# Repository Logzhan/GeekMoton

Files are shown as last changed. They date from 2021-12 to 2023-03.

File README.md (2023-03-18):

# GeekMotion

2023-03-19：经过测试发现稚晖君的Peak和GeekMotion一样存在电量显示不稳定、充电充不满的问题，计划基于Peak优化部分电路，另外发现Peak测量的电压偏低

**功能描述：类似稚晖君Peak的小组件，手持嵌入式移动终端。**

- WIFI通信功能
- IMU、MAG传感器。
- 采用原生ESP-IDF开发，移植X-Track交互框架 + LVGL。
- LettleShell命令行模块，可以采用命令行和ESP32交互。
- 计步器
- 运动识别(待实现)
- 电梯识别(待实现)
- SD卡存储

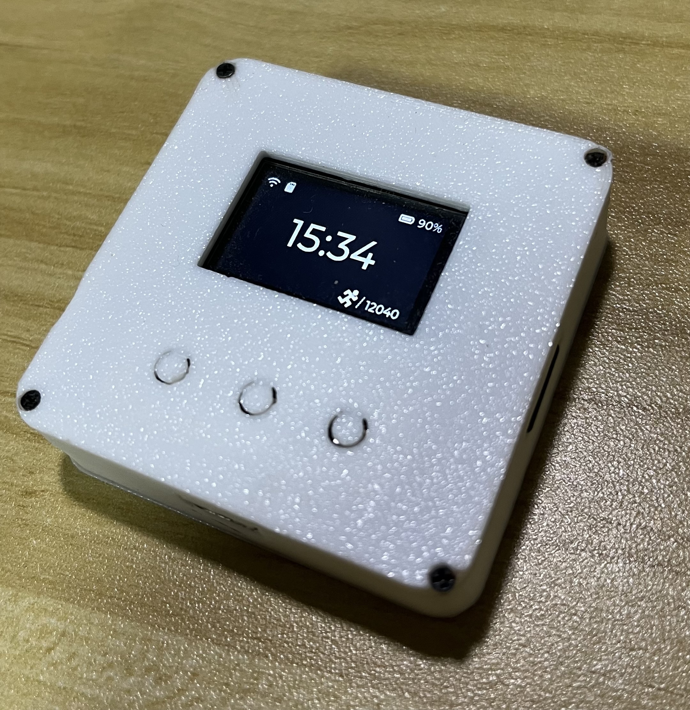
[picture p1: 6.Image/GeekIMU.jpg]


命令行支持(移植letter shell)：

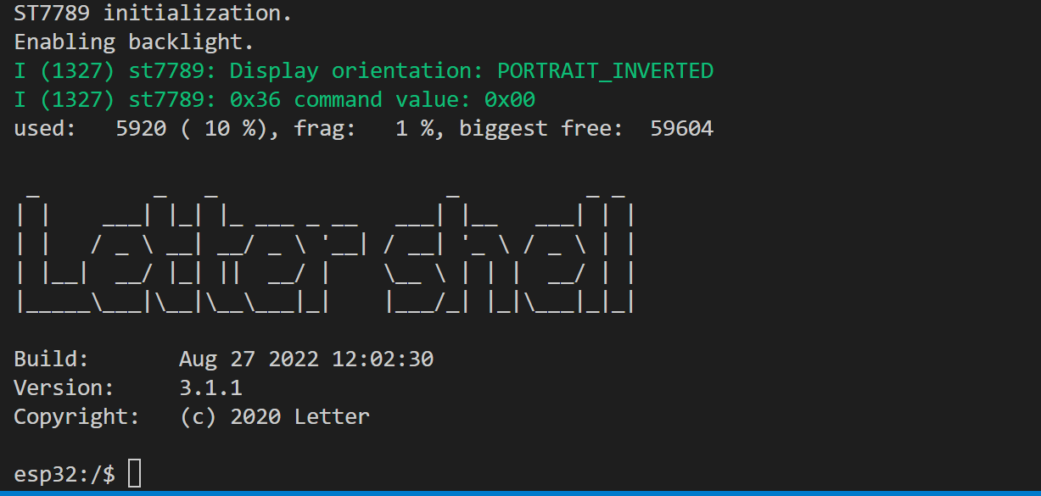
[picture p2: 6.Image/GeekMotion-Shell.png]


支持：

- 命令行自动补全
- 历史命令行记忆
- ...

**更新日志：**

**2022-08-23 ：** 1) 修改lettleSell部分函数，修改void为返回值为int, 减少由于函数指针转换造成的GCC Warning。2) 优化Page/SystemInfosModel.cpp，定义部分结构体后，采用memset函数初始化，减少GCC Warning。3）优化Page\StartUp部分宏定义、减少GCC Warning。 4）注释部分不使用函数，减少GCC Warning。

**2022-08-24 ：** 1）去掉visual studio的ARM和ARM64工程 2）隐藏LVGL在MSVC时产生的类型转换警告 3）加入CleanProject.bat脚本可以快速清理Visual Studio生成的pch和obj等临时文件。

**2022-08-27 ：**  1) 更新计步器功能 

**2022-08-28 :**    1）清除无用X-Track框架代码 2）移除Visual Studio x64工程只保留win32工程，最大程度复原Cotex-m 32位环境 

**lettleShell移植支持说明：** 需要适配esp32的ld文件。

样例：
C:\Users\Administrator\esp\esp-idf\components\esp32\ld\
在这个文件夹里面，把原来的esp32.project.ld.in替换当前目前的id文件，用于支持命令行，替换前记得备份

```c++
  /* 核心原理是找到这个.flash.appdesc, 然后加入_shell_command_start和*_shell_command_end/  
.flash.appdesc : ALIGN(0x10)
  {
    _rodata_start = ABSOLUTE(.);

    *(.rodata_desc .rodata_desc.*)               /* Should be the first.  App version info.        DO NOT PUT ANYTHING BEFORE IT! */
    *(.rodata_custom_desc .rodata_custom_desc.*) /* Should be the second. Custom app version info. DO NOT PUT ANYTHING BEFORE IT! */
	
	_shell_command_start = ABSOLUTE(.);
	KEEP (*(shellCommand))
	_shell_command_end = ABSOLUTE(.);

    /* Create an empty gap within this section. Thanks to this, the end of this
     * section will match .flah.rodata's begin address. Thus, both sections
     * will be merged when creating the final bin image. */
    . = ALIGN(ALIGNOF(.flash.rodata));
  } >default_rodata_seg
```

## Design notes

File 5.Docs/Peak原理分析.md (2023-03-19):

## Peak电路原理分析



### 一、开机电路分析

		用户在按下EC_KEY之后，EC_KEY会被拉低电平，此时Q1的栅极会被拉低电平 。此时Q1导通，单片机的系统进入有电状态，ESP32启动。此时有两种情况。1）用户立即放下按钮：此时PWR_EN还没及时拉高，Q2这个NMOS管始终处于不导通状态。Q1会处于不导通状态，系统关机。 2）用户持续按下EC_KEY此时：单片机持续运行，PWR_EN被持续拉高，Q2始终会处于导通状态，Q1的栅极会被拉低，系统始终保持有电状态。

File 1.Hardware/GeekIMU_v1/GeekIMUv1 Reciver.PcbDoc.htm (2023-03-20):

Reporting Options

# File in Previous Format

Date | : | 2023/3/20
Time | : | 21:13:47
Filename | : | Y:\Hardware Project\Geek IMU\GeekIMU v1\1.Hardware\GeekIMUv1 Reciver.PcbDoc

Version | Warning
Summer 09 | CAUTION - File contains old violation objects. These violations are no longer supported & will not be loaded. Please run DRC after opening this file in order to refresh the violations.
Summer 09 | CAUTION - Existing testpoint rules and settings are used as fabrication testpoint information.
Release 12 | CAUTION - Air Gap Width previously controlled by Clearance rule is now controlled by Polygon Connect Style rule's newly introduced Air Gap Width (set to default value). Suggest reviewing each Polygon Connect Style rule's Air Gap Width attribute for correctness.
Release 13 | CAUTION - Silkscreen Over Component Pads Rules are converted to Silk To Solder Mask Clearance Rules. Suggest examining rule scopes for accuracy.

This file was generated by an earlier version of the software

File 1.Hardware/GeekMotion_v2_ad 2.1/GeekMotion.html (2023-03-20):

Altium customize

# Board Information Report

Date: | | 2023/3/20
Time: | | 5:40:24
Elapsed Time: | | 00:00:00
Filename: | | E:\Hardware Project\GeekMotion\1.Hardware\GeekMotion_v2_ad 2.1\GeekMotion.PcbDoc
Units: | | mmmils

## Contents

Contents

Board Specification

General

Routing

Routing Information

Layer Information

Layer Information

Drill Pairs

Board Holes

Non-Plated Hole Size

Plated Hole Size

Board Slots

Non-Plated Slot Size

Plated Slot Size

Board Square Holes

Non-Plated Square Hole Size

Plated Square Hole Size

Other

Top Layer Annular Ring Size

Mid Layer Annular Ring Size

Bottom Layer Annular Ring Size

Pad Solder Mask

Pad Paste Mask

Pad Pwr/Gnd Expansion

Pad Relief Conductor Width

Pad Relief Air Gap

Pad Relief Entries

Via Solder Mask

Via Pwr/Gnd Expansion

Track Width

Arc Line Width

Arc Radius

Arc Degrees

Text Height

Text Width

Net Track Width

Net Via Size

## Board Specification

General
Board Size | 1240mils x 1340mils
Components on board | 66

Back to top

## Routing

Routing Information
Routing completion | 100.00%
Connections | 184
Connections routed | 184
Connections remaining | 0

Back to top

## Layer Information

Layer | Arcs | Pads | Vias | Tracks | Texts | Fills | Regions | ComponentBodies
Top1 | 0 | 12 | 0 | 150 | 0 | 0 | 48 | 0
Signal2 | 0 | 0 | 0 | 177 | 0 | 0 | 37 | 0
Gnd3 | 0 | 0 | 0 | 0 | 0 | 0 | 2 | 0
Bottom4 | 2 | 277 | 0 | 367 | 0 | 0 | 247 | 0
Mechanical 1 | 0 | 0 | 0 | 66 | 0 | 0 | 0 | 18
Mechanical 2 | 0 | 0 | 0 | 0 | 0 | 0 | 0 | 0
Mechanical 4 | 0 | 0 | 0 | 0 | 0 | 0 | 0 | 0
Mechanical 7 | 0 | 0 | 0 | 0 | 0 | 0 | 0 | 0
Mechanical 10 | 0 | 0 | 0 | 4 | 0 | 0 | 0 | 0
Mechanical 12 | 0 | 0 | 0 | 4 | 0 | 0 | 0 | 0
Mechanical 13 | 0 | 0 | 0 | 296 | 0 | 0 | 0 | 48
Mechanical 14 | 0 | 0 | 0 | 184 | 1 | 0 | 2 | 0
Mechanical 15 | 0 | 0 | 0 | 48 | 0 | 0 | 0 | 0
Top Paste | 0 | 0 | 0 | 0 | 0 | 0 | 0 | 0
Top Overlay | 0 | 0 | 0 | 5 | 7 | 0 | 0 | 0
Top Solder | 0 | 0 | 0 | 0 | 2 | 1 | 0 | 0
Bottom Solder | 0 | 0 | 0 | 0 | 0 | 1 | 0 | 0
Bottom Overlay | 7 | 0 | 0 | 454 | 132 | 0 | 94 | 0
Bottom Paste | 0 | 0 | 0 | 0 | 0 | 0 | 0 | 0
Drill Guide | 0 | 0 | 0 | 0 | 0 | 0 | 0 | 0
Keep-Out Layer | 0 | 0 | 0 | 4 | 0 | 0 | 0 | 0
Drill Drawing | 0 | 0 | 0 | 0 | 0 | 0 | 0 | 0
Multi-Layer | 0 | 6 | 224 | 0 | 0 | 0 | 1 | 0
Total | 9 | 295 | 224 | 1759 | 142 | 2 | 431 | 66

Back to top

Drill Pairs | Vias
Top1 - Bottom4 | 224
Total | 224

Back to top

## Board Holes

Non-Plated Hole Size | Pads | Vias
Total | 0 | 0

Back to top

Plated Hole Size | Pads | Vias
0mils | 279 | 0
10mils | 0 | 220
25.591mils | 2 | 0
39.37mils | 0 | 2
62.992mils | 0 | 2
Total | 281 | 224

Back to top

## Board Slots

Non-Plated Slot Size / Length | Pads
Total | 0

Back to top

Plated Slot Size / Length | Pads
23.622mil / 47.244mil | 2
23.622mil / 66.929mil | 2
Total | 4

Back to top

## Board Square Holes

Non-Plated Square Hole Size | Pads
Total | 0

Back to top

Plated Square Hole Size | Pads
Total | 0

Back to top

## Other

Top Layer Annular Ring Size | Count
0mils | 6
8mils | 23
10mils | 197
39.37mils | 2
59.055mils | 2
Total | 230

Back to top

Mid Layer Annular Ring Size | Count
0mils | 6
8mils | 23
10mils | 197
39.37mils | 2
59.055mils | 2
Total | 230

Back to top

Bottom Layer Annular Ring Size | Count
0mils | 6
8mils | 23
10mils | 197
39.37mils | 2
59.055mils | 2
Total | 230

Back to top

Pad Solder Mask | Count
0mils | 6
3mils | 261
5mils | 28
Total | 295

Back to top

Pad Paste Mask | Count
0mils | 295
Total | 295

Back to top

Pad Pwr/Gnd Expansion | Count
8mils | 295
Total | 295

Back to top

Pad Relief Conductor Width | Count
10mils | 295
Total | 295

Back to top

Pad Relief Air Gap | Count
10mils | 295
Total | 295

Back to top

Pad Relief Entries | Count
4 | 295
Total | 295

Back to top

Via Solder Mask | Count
3mils | 224
Total | 224

Back to top

Via Pwr/Gnd Expansion | Count
8mils | 224
Total | 224

Back to top

Track Width | Count
0mils | 60
1mils | 360
2mils | 456
3.937mils | 68
3.94mils | 7
4mils | 390
5mils | 20
5.906mils | 4
6mils | 155
7mils | 2
7.874mils | 42
8mils | 5
10mils | 129
15mils | 61
Total | 1759

Back to top

Arc Line Width | Count
6mils | 1
9.843mils | 2
10mils | 6
Total | 9

Back to top

Arc Radius | Count
3mils | 1
4.921mils | 2
32.153mils | 1
34.143mils | 1
165.354mils | 4
Total | 9

Back to top

Arc Degrees | Count
10 | 2
33 | 2
45 | 2
360 | 3
Total | 9

Back to top

Text Height | Count
40mils | 1
50mils | 3
55mils | 1
60mils | 132
70mils | 1
90mils | 1
100mils | 1
140mils | 2
Total | 142

Back to top

Text Width | Count
4mils | 1
10mils | 141
Total | 142

Back to top

Net Track Width | Count
4mils | 65
Total | 65

Back to top

Net Via Size | Count
16mils | 65
Total | 65

Back to top

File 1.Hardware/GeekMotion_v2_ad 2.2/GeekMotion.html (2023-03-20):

Altium customize

# Board Information Report

Date: | | 2023/3/20
Time: | | 23:54:33
Elapsed Time: | | 00:00:00
Filename: | | E:\Hardware Project\GeekMotion\1.Hardware\GeekMotion_v2_ad 2.2\GeekMotion.PcbDoc
Units: | | mmmils

## Contents

Contents

Board Specification

General

Routing

Routing Information

Layer Information

Layer Information

Drill Pairs

Board Holes

Non-Plated Hole Size

Plated Hole Size

Board Slots

Non-Plated Slot Size

Plated Slot Size

Board Square Holes

Non-Plated Square Hole Size

Plated Square Hole Size

Other

Top Layer Annular Ring Size

Mid Layer Annular Ring Size

Bottom Layer Annular Ring Size

Pad Solder Mask

Pad Paste Mask

Pad Pwr/Gnd Expansion

Pad Relief Conductor Width

Pad Relief Air Gap

Pad Relief Entries

Via Solder Mask

Via Pwr/Gnd Expansion

Track Width

Arc Line Width

Arc Radius

Arc Degrees

Text Height

Text Width

Net Track Width

Net Via Size

## Board Specification

General
Board Size | 1240mils x 1340mils
Components on board | 70

Back to top

## Routing

Routing Information
Routing completion | 100.00%
Connections | 191
Connections routed | 191
Connections remaining | 0

Back to top

## Layer Information

Layer | Arcs | Pads | Vias | Tracks | Texts | Fills | Regions | ComponentBodies
Top1 | 0 | 12 | 0 | 159 | 0 | 0 | 45 | 0
Signal2 | 0 | 0 | 0 | 177 | 0 | 0 | 38 | 0
Gnd3 | 0 | 0 | 0 | 0 | 0 | 0 | 2 | 0
Bottom4 | 2 | 285 | 0 | 390 | 0 | 0 | 224 | 0
Mechanical 1 | 0 | 0 | 0 | 66 | 0 | 0 | 0 | 17
Mechanical 2 | 0 | 0 | 0 | 0 | 0 | 0 | 0 | 0
Mechanical 4 | 0 | 0 | 0 | 0 | 0 | 0 | 0 | 0
Mechanical 7 | 0 | 0 | 0 | 0 | 0 | 0 | 0 | 0
Mechanical 10 | 0 | 0 | 0 | 4 | 0 | 0 | 0 | 0
Mechanical 12 | 0 | 0 | 0 | 4 | 0 | 0 | 0 | 0
Mechanical 13 | 0 | 0 | 0 | 326 | 0 | 0 | 0 | 53
Mechanical 14 | 0 | 0 | 0 | 204 | 1 | 0 | 2 | 0
Mechanical 15 | 0 | 0 | 0 | 42 | 0 | 0 | 0 | 0
Top Paste | 0 | 0 | 0 | 0 | 0 | 0 | 0 | 0
Top Overlay | 0 | 0 | 0 | 5 | 7 | 0 | 0 | 0
Top Solder | 0 | 0 | 0 | 0 | 2 | 1 | 0 | 0
Bottom Solder | 0 | 0 | 0 | 0 | 0 | 5 | 0 | 0
Bottom Overlay | 6 | 0 | 0 | 487 | 140 | 0 | 104 | 0
Bottom Paste | 0 | 0 | 0 | 0 | 0 | 0 | 0 | 0
Drill Guide | 0 | 0 | 0 | 0 | 0 | 0 | 0 | 0
Keep-Out Layer | 0 | 0 | 0 | 4 | 0 | 0 | 0 | 0
Drill Drawing | 0 | 0 | 0 | 0 | 0 | 0 | 0 | 0
Multi-Layer | 0 | 6 | 223 | 0 | 0 | 0 | 1 | 0
Total | 8 | 303 | 223 | 1868 | 150 | 6 | 416 | 70

Back to top

Drill Pairs | Vias
Top1 - Bottom4 | 223
Total | 223

Back to top

## Board Holes

Non-Plated Hole Size | Pads | Vias
Total | 0 | 0

Back to top

Plated Hole Size | Pads | Vias
0mils | 287 | 0
10mils | 0 | 219
25.591mils | 2 | 0
39.37mils | 0 | 2
62.992mils | 0 | 2
Total | 289 | 223

Back to top

## Board Slots

Non-Plated Slot Size / Length | Pads
Total | 0

Back to top

Plated Slot Size / Length | Pads
23.622mil / 47.244mil | 2
23.622mil / 66.929mil | 2
Total | 4

Back to top

## Board Square Holes

Non-Plated Square Hole Size | Pads
Total | 0

Back to top

Plated Square Hole Size | Pads
Total | 0

Back to top

## Other

Top Layer Annular Ring Size | Count
0mils | 6
8mils | 21
10mils | 198
39.37mils | 2
59.055mils | 2
Total | 229

Back to top

Mid Layer Annular Ring Size | Count
0mils | 6
8mils | 21
10mils | 198
39.37mils | 2
59.055mils | 2
Total | 229

Back to top

Bottom Layer Annular Ring Size | Count
0mils | 6
8mils | 21
10mils | 198
39.37mils | 2
59.055mils | 2
Total | 229

Back to top

Pad Solder Mask | Count
0mils | 6
3mils | 269
5mils | 28
Total | 303

Back to top

Pad Paste Mask | Count
0mils | 303
Total | 303

Back to top

Pad Pwr/Gnd Expansion | Count
8mils | 303
Total | 303

Back to top

Pad Relief Conductor Width | Count
10mils | 303
Total | 303

Back to top

Pad Relief Air Gap | Count
10mils | 303
Total | 303

Back to top

Pad Relief Entries | Count
4 | 303
Total | 303

Back to top

Via Solder Mask | Count
3mils | 223
Total | 223

Back to top

Via Pwr/Gnd Expansion | Count
8mils | 223
Total | 223

Back to top

Track Width | Count
0mils | 60
1mils | 392
2mils | 506
3.937mils | 62
3.94mils | 7
4mils | 410
5mils | 20
5.906mils | 4
6mils | 160
7mils | 2
7.874mils | 34
8mils | 20
10mils | 130
15mils | 61
Total | 1868

Back to top

Arc Line Width | Count
6mils | 1
9.843mils | 1
10mils | 6
Total | 8

Back to top

Arc Radius | Count
3mils | 1
4.921mils | 1
32.153mils | 1
34.143mils | 1
165.354mils | 4
Total | 8

Back to top

Arc Degrees | Count
10 | 2
33 | 2
45 | 2
360 | 2
Total | 8

Back to top

Text Height | Count
40mils | 1
50mils | 3
55mils | 1
60mils | 140
70mils | 1
90mils | 1
100mils | 1
140mils | 2
Total | 150

Back to top

Text Width | Count
4mils | 1
10mils | 149
Total | 150

Back to top

Net Track Width | Count
4mils | 67
Total | 67

Back to top

Net Via Size | Count
16mils | 67
Total | 67

Back to top

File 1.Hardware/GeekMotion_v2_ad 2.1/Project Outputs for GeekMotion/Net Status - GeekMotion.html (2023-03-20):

Altium customize

# Net Status Report

Date: | | 2023/3/20
Time: | | 4:50:46
Elapsed Time: | | 00:00:00
Filename: | | E:\Hardware Project\GeekMotion\1.Hardware\GeekMotion_v2_ad 2.1\GeekMotion.PcbDoc
Units: | | mmmils

Nets | Layer | Length
3V3A | Signal Layers Only | 1722.292mils
BAT_DET | Signal Layers Only | 2388.11mils
BOOT | Signal Layers Only | 775.689mils
BUZZ | Signal Layers Only | 1140.441mils
CHG_DET | Signal Layers Only | 1880.613mils
CP_Rx | Signal Layers Only | 1344.729mils
CP_Tx | Signal Layers Only | 447.609mils
DTR | Signal Layers Only | 778.915mils
EC_A | Signal Layers Only | 956.258mils
EC_B | Signal Layers Only | 796.064mils
EC_KEY | Signal Layers Only | 628.989mils
EC_KEY_DET | Signal Layers Only | 1810.437mils
ESP_EN | Signal Layers Only | 233.519mils
FLASH_CLK | Signal Layers Only | 0mils
FLASH_CS | Signal Layers Only | 0mils
FLASH_SD0 | Signal Layers Only | 0mils
FLASH_SD1 | Signal Layers Only | 0mils
FLASH_SD2 | Signal Layers Only | 0mils
FLASH_SD3 | Signal Layers Only | 0mils
GND | Signal Layers Only | 1186.448mils
GPIO10 | Signal Layers Only | 0mils
GPIO12 | Signal Layers Only | 1292.302mils
GPIO13 | Signal Layers Only | 746.275mils
GPIO14 | Signal Layers Only | 844.795mils
GPIO15 | Signal Layers Only | 528.15mils
GPIO18 | Signal Layers Only | 1405.995mils
GPIO19 | Signal Layers Only | 0mils
GPIO2 | Signal Layers Only | 989.183mils
GPIO21 | Signal Layers Only | 1147.734mils
GPIO22 | Signal Layers Only | 880.544mils
GPIO23 | Signal Layers Only | 1451.907mils
GPIO26 | Signal Layers Only | 1349.258mils
GPIO32 | Signal Layers Only | 897.61mils
GPIO33 | Signal Layers Only | 880.424mils
GPIO4 | Signal Layers Only | 938.163mils
GPIO5 | Signal Layers Only | 0mils
GPIO9 | Signal Layers Only | 0mils
LCD_LEDK | Signal Layers Only | 381.86mils
NetA1_1 | Signal Layers Only | 164.808mils
NetC13_1 | Signal Layers Only | 90.27mils
NetC14_2 | Signal Layers Only | 103.318mils
NetC3_2 | Signal Layers Only | 41.971mils
NetD1_1 | Signal Layers Only | 377.671mils
NetD3_2 | Signal Layers Only | 169.335mils
NetD4_2 | Signal Layers Only | 30mils
NetQ3_2 | Signal Layers Only | 94.72mils
NetQ3_5 | Signal Layers Only | 91.406mils
NetQ4_3 | Signal Layers Only | 150.268mils
NetQ5_3 | Signal Layers Only | 57.205mils
NetR10_2 | Signal Layers Only | 1310.914mils
NetR15_2 | Signal Layers Only | 68.615mils
NetR16_1 | Signal Layers Only | 93.812mils
NetR1_2 | Signal Layers Only | 49.452mils
NetR6_2 | Signal Layers Only | 602.265mils
NetR8_1 | Signal Layers Only | 43.203mils
RTS | Signal Layers Only | 734.365mils
SENSOR_VN | Signal Layers Only | 0mils
SENSOR_VP | Signal Layers Only | 0mils
USB-PWR-DM | Signal Layers Only | 320.227mils
USB-PWR-DP | Signal Layers Only | 337.384mils
VBAT | Signal Layers Only | 1068.653mils
VCC_3V3 | Signal Layers Only | 3380.403mils
VCC_SYS | Signal Layers Only | 487.459mils
VCC_SYS_IN | Signal Layers Only | 2246.025mils
VUSB | Signal Layers Only | 2049.007mils

Back to top

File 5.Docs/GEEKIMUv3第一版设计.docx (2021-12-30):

GEEKIMUv3 第一版硬件设计

1、 功能设计
1. WIFI & 蓝牙通信 & MCU 主控制
2. OLED显示
3. 按键功能
4. 姿态检测
5. 锂电池充电
6. 电压检测
7. SD卡读取与存储

二、

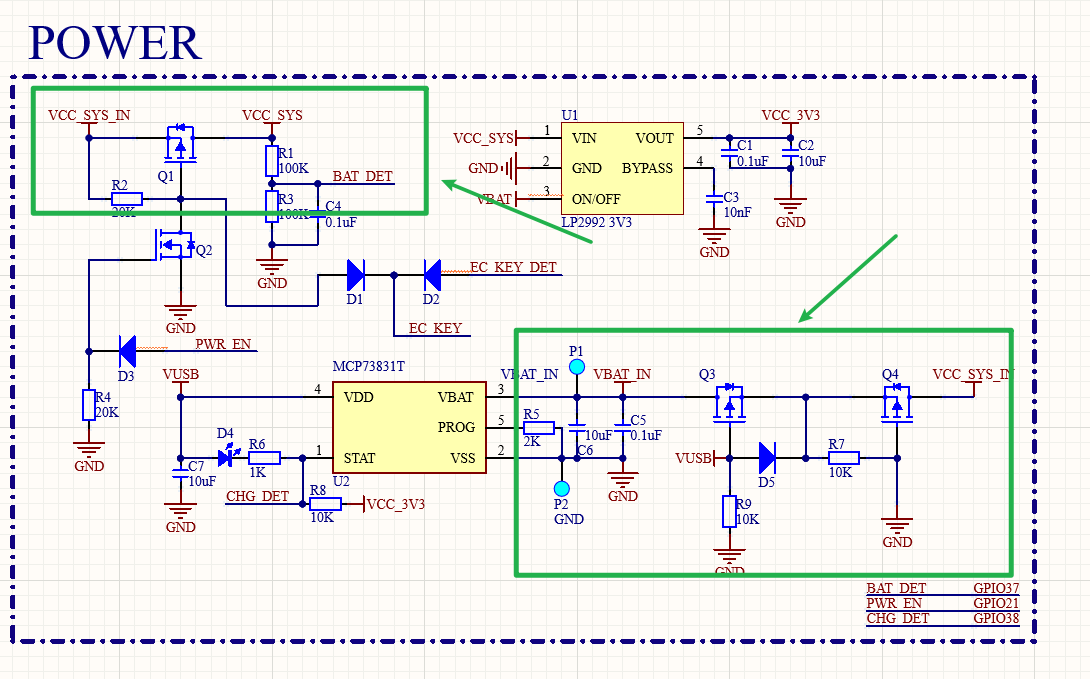
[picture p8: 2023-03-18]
5.Docs/Peak改进电路.png

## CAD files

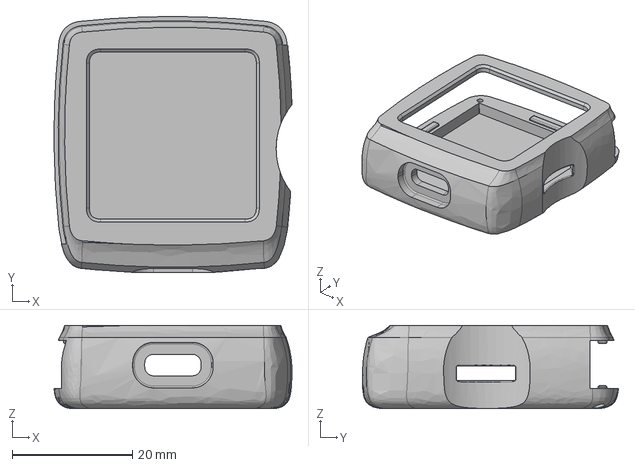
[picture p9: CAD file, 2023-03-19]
4.3D Model/主件.step
39.5 x 42.5 x 13.8 mm

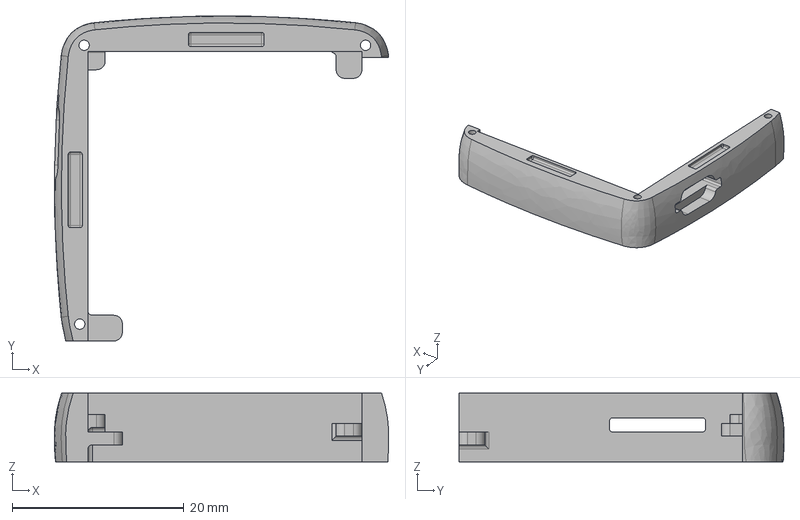
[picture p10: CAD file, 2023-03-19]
4.3D Model/侧件.step
38.9 x 37.8 x 8.00 mm

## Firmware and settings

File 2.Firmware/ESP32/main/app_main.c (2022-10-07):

/******************** (C) COPYRIGHT 2020 GEEKIMU *******************************
* File Name          : geekimu_main.c
* Current Version    : V1.0  & ESP32
* Author             : zhanli 719901725@qq.com & JustFeng.
* Date of Issued     : 2021.7.20 zhanli : Create
* Comments           : GEEKIMUv3主程序
********************************************************************************/
#include <stdio.h>
#include <string.h>
#include <stdint.h>
#include "sdkconfig.h"
#include "freertos/FreeRTOS.h"
#include "freertos/task.h"
#include "HAL/HAL.h"

// ESP网络相关
#include "esp_log.h"
#include "lwip/err.h"
#include "lwip/sys.h"
#include <sys/param.h>
#include "esp_netif.h"
#include "lwip/sockets.h"
#include <lwip/netdb.h>
// ESP 串口配置相关
#include "freertos/queue.h"
#include "geek_shell_api.h"

// ADC 配置相关
#include "esp_freertos_hooks.h"
#include "freertos/semphr.h"

#include "lvgl.h"
#include "lvgl_helpers.h"
#include "System/GeekOS.h"
#include "WIFINetwork.h"
#include "mpu9250.h"

/**********************
 *  LVGL Support.
 **********************/
#define LV_TICK_PERIOD_MS 1
static void lv_tick_task(void *arg);
static void guiTask(void *pvParameter);

#define UDP_PORT            9000
#define TAG                 "main"

/**-----------------------------------------------------------------------
* Function    : app_main
* Description : GEEKIMU 程序主入口
* Author      : zhanli&719901725@qq.com
* Date        : 2021/7/20 zhanli
*---------------------------------------------------------------------**/
void app_main(void)
{
    /* HAL init config. */
    HAL_Init();
    /* Create LVGL GUI task. */
    xTaskCreatePinnedToCore(guiTask, "gui", 4096*8, NULL, 0, NULL, 1);

    /* Run letter shell cmd. */
    vTaskDelay(1500 / portTICK_PERIOD_MS);
    /* Config serial zero for shell. */
	userShellInit(0);
    xTaskCreate(shellTask, "shell", 4096, getEsp32Shell(), 12, NULL);
    
    // Network_Init();
    // xTaskCreate(Network_UdpSendData, "NetworkSendData", 4096, NULL, 5, NULL);

    /* Forever loop. */
    while(1){
        /* Delay 10ms in order to relase cpu. */
        vTaskDelay(10 / portTICK_PERIOD_MS);
        /* Update HAL task. */
        HAL_Update(lv_tick_get());
    }
}

/* Will be called by the library to read the encoder */
void keypad_read(lv_indev_drv_t* indev_drv, lv_indev_data_t* data)
{
    Button_Info_t info;
    Button_GetInfo(&info);
    data->enc_diff = info.btnUp - info.btnDown;
    int16_t isPush = info.btnOK;
    data->state = isPush ? LV_INDEV_STATE_PRESSED : LV_INDEV_STATE_RELEASED;
}

/* Creates a semaphore to handle concurrent call to lvgl stuff
 * If you wish to call *any* lvgl function from other threads/tasks
 * you should lock on the very same semaphore! */
SemaphoreHandle_t xGuiSemaphore;

static void guiTask(void *pvParameter) {

    (void) pvParameter;
    xGuiSemaphore = xSemaphoreCreateMutex();

    lv_init();
    // 初始化LCD显示驱动
    lvgl_driver_init();

    /* malloc display buffer */
    lv_color_t* buf1 = heap_caps_malloc(DISP_BUF_SIZE * sizeof(lv_color_t), MALLOC_CAP_DMA);
    assert(buf1 != NULL);
    /* rgb color screen recomand use double buff */
    lv_color_t* buf2 = heap_caps_malloc(DISP_BUF_SIZE * sizeof(lv_color_t), MALLOC_CAP_DMA);
    assert(buf2 != NULL);

    static lv_disp_draw_buf_t disp_buf;
    uint32_t size_in_px = DISP_BUF_SIZE;
    /* Initialize the working buffer depending on the selected display.
     * NOTE: buf2 == NULL when using monochrome displays. */
    lv_disp_draw_buf_init(&disp_buf, buf1, buf2, size_in_px);

    static lv_disp_drv_t disp_drv;         /*A variable to hold the drivers. Must be static or global.*/
    lv_disp_drv_init(&disp_drv);           /*Basic initialization*/
    disp_drv.draw_buf = &disp_buf;         /*Set an initialized buffer*/
    disp_drv.flush_cb = disp_driver_flush; /*Set a flush callback to draw to the display*/
    disp_drv.hor_res = LV_HOR_RES_MAX;     /*Set the horizontal resolution in pixels*/
    disp_drv.ver_res = LV_VER_RES_MAX;     /*Set the vertical resolution in pixels*/
    lv_disp_drv_register(&disp_drv);       /*Register the driver and save the created display objects*/

    static lv_indev_drv_t indev_drv;

    /*Register a encoder input device*/
    lv_indev_drv_init(&indev_drv);
    indev_drv.type = LV_INDEV_TYPE_ENCODER;
    indev_drv.read_cb = keypad_read;
    lv_indev_t* indev = lv_indev_drv_register(&indev_drv);

    lv_group_t* group = lv_group_create();
    if (group){
        lv_group_set_default(group);
        lv_indev_set_group(indev, group);
    }
    /* Create and start a periodic timer interrupt to call lv_tick_inc */
    const esp_timer_create_args_t periodic_timer_args = {
        .callback = &lv_tick_task,
        .name = "periodic_gui"
    };
    esp_timer_handle_t periodic_timer;
    ESP_ERROR_CHECK(esp_timer_create(&periodic_timer_args, &periodic_timer));
    ESP_ERROR_CHECK(esp_timer_start_periodic(periodic_timer, LV_TICK_PERIOD_MS * 1000));

    // 启动GEEK GUI
    GeekOS_Init();

    while (1) {
        /* Delay 1 tick (assumes FreeRTOS tick is 10ms */
        vTaskDelay(pdMS_TO_TICKS(10));
        /* Try to take the semaphore, call lvgl related function on success */
        if (pdTRUE == xSemaphoreTake(xGuiSemaphore, portMAX_DELAY)) {
            lv_task_handler();
            xSemaphoreGive(xGuiSemaphore);
       }
    }
    /* A task should NEVER return */
    free(buf1);
    free(buf2);
    vTaskDelete(NULL);
}

static void lv_tick_task(void *arg) {
    (void) arg;
    lv_tick_inc(LV_TICK_PERIOD_MS);
}

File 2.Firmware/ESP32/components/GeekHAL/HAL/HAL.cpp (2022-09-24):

#include <stdio.h>
#include "HAL.h"
#include "System/Version.h"
#include "MillisTaskManager/MillisTaskManager.h"

#ifdef _WIN32
#include <windows.h>
#include <time.h>
#define millis        clock
#else
#include "freertos/FreeRTOS.h"
#include "freertos/task.h"
#define millis        xTaskGetTickCount
#endif

static MillisTaskManager taskManager;

#if CONFIG_SENSOR_ENABLE

static void HAL_Sensor_Init()
{
#if CONFIG_SENSOR_IMU_ENABLE
    IMU_Init();
#endif

#if CONFIG_SENSOR_MAG_ENABLE
    MAG_Init();
#endif
}

#endif

// static void HAL_TimerInterrputUpdate()
// {

// }

void HAL_Init()
{
    Config_Init();
    SD_Init();
    Power_Init();
    Button_Init();

#if CONFIG_SENSOR_ENABLE
    HAL_Sensor_Init();
#endif

#ifndef _WIN32
    ShellSupport_Init();
#endif

    taskManager.Register(Power_Update, 1000);
    taskManager.Register(Button_Update, 10);
    taskManager.Register(IMU_Update, 10);
    taskManager.Register(MAG_Update, 10);
}

void HAL_Update(uint32_t tick)
{
    taskManager.Running(tick);
}

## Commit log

2021-07-20 GEEKIMUv3固件调试代码
    [partitions_example.csv]
2021-07-21 增加ESP32的shell功能
2021-07-21 GEEKIMUv3增加letter shell命令行
2021-07-22 增加命令行导出,增加文件读写
2021-07-23 增加wifi配置修改功能
2021-10-18 增加SD卡组件支持
2021-10-28 优化iic代码，独立adc采样模块，增加imu数据存储sdcard
2021-10-31 修复编译器警告，优化部分函数注释
2021-11-15 增加1.14寸ips屏幕驱动
2021-11-15 增加硬件设计原理图和PCB
2021-11-16 增加MPU9250 硬件iic驱动
2021-12-13 更新固件和硬件
2021-12-23 add lvgl support
    [code-format.cfg]
2021-12-23 合并GEEKIMU和LVGL工程
    [code-format.cfg]
2021-12-28 增加visual studio 仿真器支持
2021-12-30 增加GEEKIMUv3主界面LVGL显示
2022-01-05 清除lvgl无关文件，修复little Shell 命令打印不对齐的问题，优化整理代码结构
    [partitions.csv]
2022-01-06 移植FASTSHIFT/watchX的Button Event驱动,采用C调用cpp的方式，方便后续的代码移植
2022-01-12 增加lvgl v8的支持
    [partitions.csv]
2022-01-12 更换lvgl到8.1版本
    [partitions.csv]
2022-01-12 增加X-Track仿真器
2022-08-04 lvgl的仿真器适配GEEKIMU
    [partitions.csv]
2022-08-08 移植x-track框架，优化仿真器
2022-08-10 修复崩溃问题
    [partitions.csv]
2022-08-15 优化目录结构、适配电池和SD卡的HAL层
2022-08-18 回复分支
2022-08-22 修复未安装SDK卡导死机BUG，接入虚拟IMU和MAG数据，启动DataProc模块
2022-08-23 优化代码，清除Warning
2022-08-23 修复readme.md文件错误
2022-08-24 优化Visual Studio工程，加入VS工程清理脚本，隐藏MSVC编译LVGL的类型警告
2022-08-27 增加计步器、增加HAL_Shell方便Shell调用HAL层cpp函数
2022-08-28 删除无用X-Track代码，删除VS x64工程，仅保留win32
2022-09-09 更新README.md
2022-09-24 修复README.md图片路径问题
2022-09-24 更新网络部分
    [geek_partitions.csv]
2022-10-06 优化底层驱动功能
2022-10-07 注释wifi部分，防止因为启动wifi电流不够无限重启
2023-03-18 更新后续几哈
2023-03-19 移植Peak的设计图到GeekMotion
    [GeekMotion.PrjPCB, Main.SchDoc, 主件.step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]
2023-03-20 修改IMU为MPU9250
    [GEEKIMUv1.PrjPCB, GeekIMU.SCHLIB, GeekIMUv1 Reciver.PcbDoc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]
